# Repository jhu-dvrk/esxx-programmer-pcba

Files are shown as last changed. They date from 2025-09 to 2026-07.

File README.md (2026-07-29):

# ESXX Programmer PCB

This repository contains the KiCad design files for the ESXX Programmer board (previously called ESPM Programmer). This board was originally developed to reprogram the FPGA on the ESPM board inside the PSM and ECM in the dVRK-Si system.

It is now also used to reprogram the FPGA on the ESSJ board inside the PSM and ECM setup joints in a full dVRK-Si system.

This board is connected to the JTAG port on the ESPM or ESSJ via a custom cable. Instructions for making the cable are in `dvrk-s-programmer-cable.pptx`.

The current firmware for this board is in [this repository](https://github.com/jhu-dvrk/esxx-programmer-firmware).  Previous versions (for ESPM Programmer) have been archived [here](https://github.com/jhu-dvrk/espm-programmer-firmware).

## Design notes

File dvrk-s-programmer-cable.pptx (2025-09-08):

## Wire harness assy, ESPM programmer

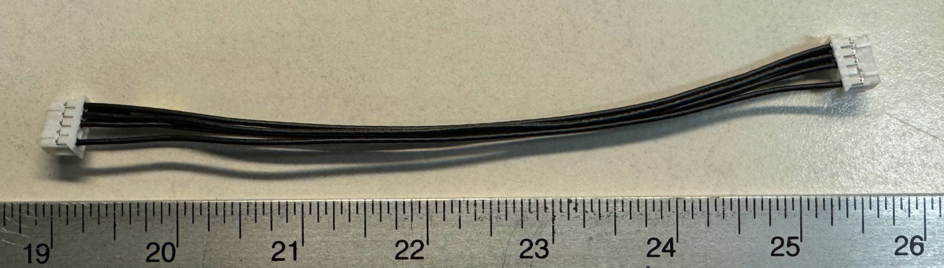
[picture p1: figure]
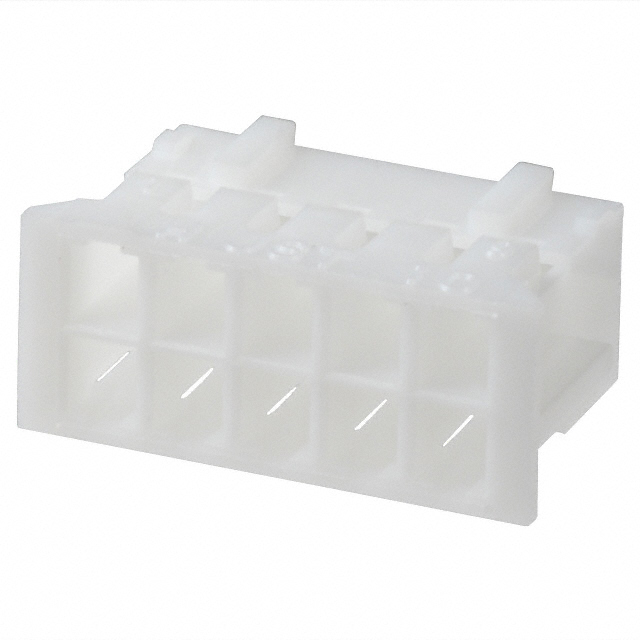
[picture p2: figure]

455-1158-ND
JST PHD 2x5
Qty 2

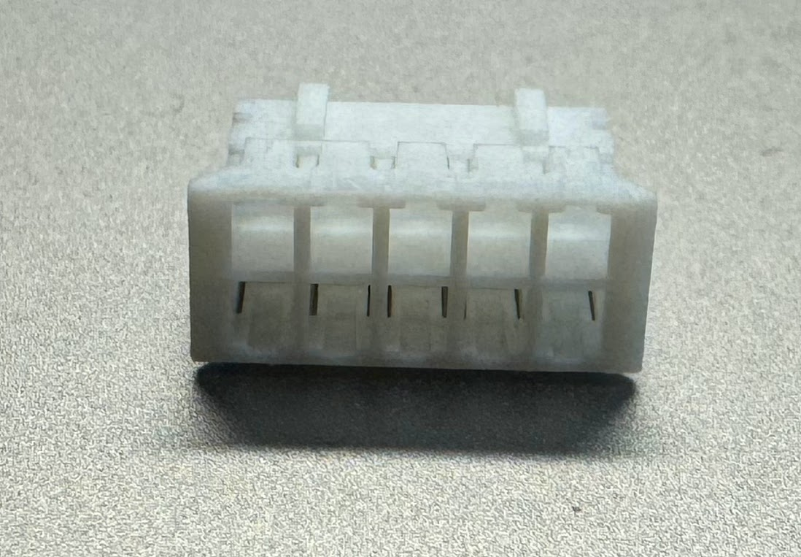
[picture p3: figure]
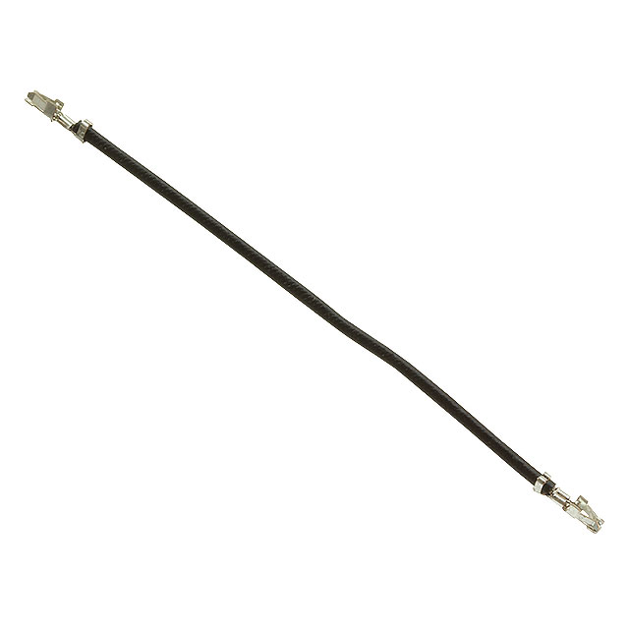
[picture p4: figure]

Precrimped
455-3085-ND
PHD 24 AWG
Qty 6

Apply a 10 mm section of yellow heat shrink tube on this end

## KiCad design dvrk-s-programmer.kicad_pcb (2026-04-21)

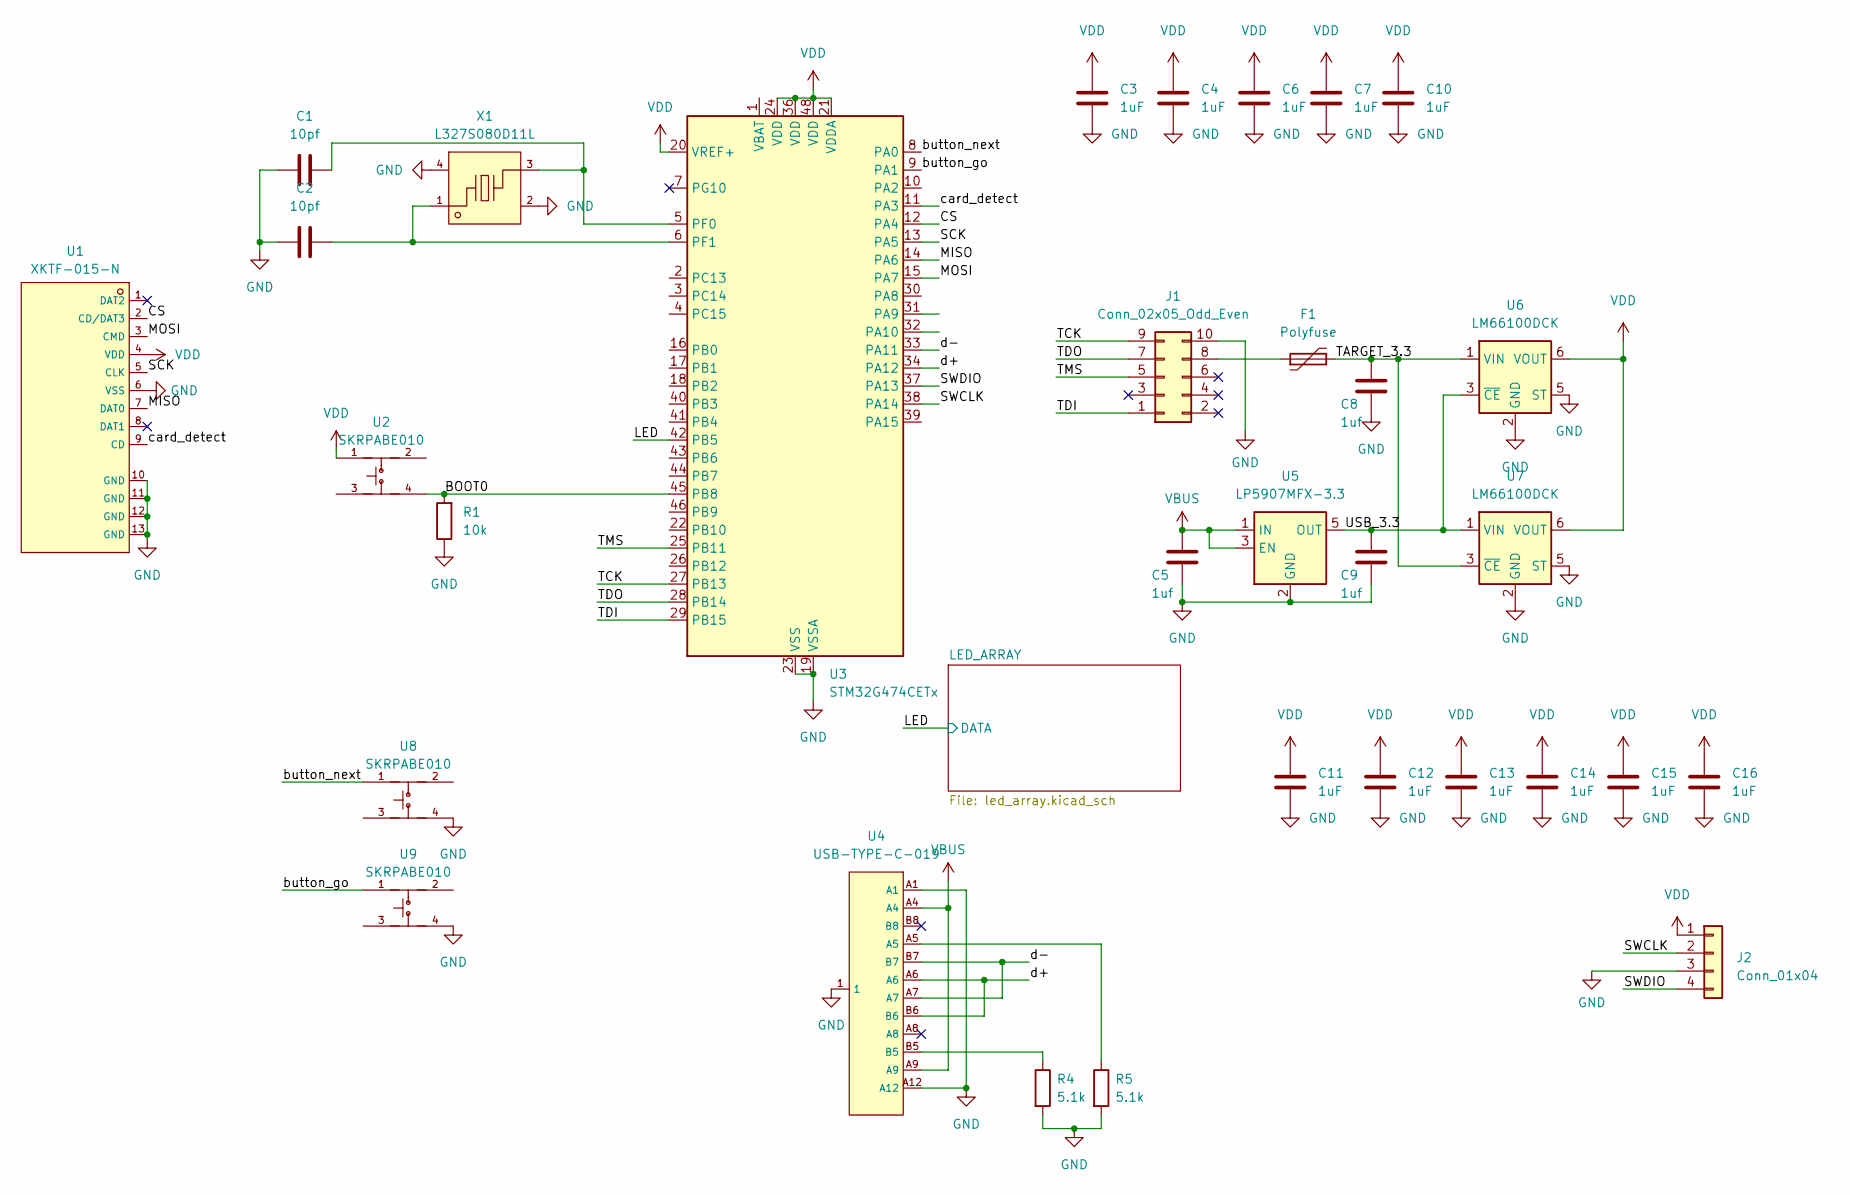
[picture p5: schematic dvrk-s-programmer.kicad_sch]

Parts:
C1, C2: 10pf; C_0402_1005Metric; LCSC C32949
C3, C4, C6, C7, C10, C11, C12, C13, C14, C15, C16: 1uF; C_0402_1005Metric
C5, C8, C9: 1uf; C_0402_1005Metric; LCSC C52923
F1: Polyfuse; Fuse_0805_2012Metric
J1: Conn_02x05_Odd_Even; JST_PHD_S10B-PHDSS_2x05_P2.00mm_Horizontal
J2: Conn_01x04; PinHeader_1x04_P2.54mm_Vertical
R1: 10k; R_0402_1005Metric; LCSC C25744
R4, R5: 5.1k; R_0402_1005Metric; LCSC C25905
U1: XKTF-015-N; TF-SMD_XKTF-015-N; LCSC C381082
U2, U8, U9: SKRPABE010; KEY-SMD_4P-L4.2-W3.2-P2.20-LS4.6; LCSC C115360
U3: STM32G474CETx; LQFP-48_7x7mm_P0.5mm; LCSC C730125
U4: USB-TYPE-C-019; TYPE-C-SMD_HX-TYPE-C-16PIN; LCSC C2927039
U5: LP5907MFX-3.3; SOT-23-5; LCSC C80670
U6, U7: LM66100DCK; SOT-363_SC-70-6
X1: L327S080D11L; CRYSTAL-SMD_4P-L3.2-W2.5-BL; LCSC C5261255

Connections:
/BOOT0: R1.2, U2.4, U3.45 (PB8)
/CS: U1.2 (CD/DAT3), U3.12 (PA4)
/LED: U3.42 (PB5); also elsewhere on the board
/MISO: U1.7 (DAT0), U3.14 (PA6)
/MOSI: U1.3 (CMD), U3.15 (PA7)
/SCK: U1.5 (CLK), U3.13 (PA5)
/SWCLK: J2.2, U3.38 (PA14)
/SWDIO: J2.4, U3.37 (PA13)
/TARGET_3.3: C8.2, F1.2, U6.1 (VIN), U7.3 (~CE)
/TCK: J1.9, U3.27 (PB13)
/TDI: J1.1, U3.29 (PB15)
/TDO: J1.7, U3.28 (PB14)
/TMS: J1.5, U3.25 (PB11)
/USB_3.3: C9.2, U5.5 (OUT), U6.3 (~CE), U7.1 (VIN)
/button_go: U3.9 (PA1), U9.1
/button_next: U3.8 (PA0), U8.1
/card_detect: U1.9 (CD), U3.11 (PA3)
/d+: U3.34 (PA12), U4.A6, U4.B6
/d-: U3.33 (PA11), U4.A7, U4.B7
GND: C1.1, C2.1, C3.2, C4.2, C5.1, C6.2, C7.2, C8.1, C9.1, C10.2, C11.2, C12.2, C13.2, C14.2, C15.2, C16.2, J1.10, J2.3, R1.1, R4.2, R5.2, U1.6 (VSS), U1.10 (GND), U1.11 (GND), U1.12 (GND), U1.13 (GND), U3.19 (VSSA), U3.23 (VSS), U3.35 (VSS), U3.47 (VSS), U4.1, U4.A1, U4.A12, U5.2 (GND), U6.2 (GND), U6.5 (ST), U7.2 (GND), U7.5 (ST), U8.4, U9.4, X1.2 (GND), X1.4 (GND); also elsewhere on the board
unnamed: F1.1, J1.8
unnamed: R4.1, U4.B5
unnamed: R5.1, U4.A5
unnamed: C1.2, U3.5 (PF0), X1.3
unnamed: C2.2, U3.6 (PF1), X1.1
VBUS: C5.2, U4.A4, U4.A9, U5.1 (IN), U5.3 (EN)
VDD: C3.1, C4.1, C6.1, C7.1, C10.1, C11.1, C12.1, C13.1, C14.1, C15.1, C16.1, J2.1, U1.4 (VDD), U2.1, U3.20 (VREF+), U3.21 (VDDA), U3.24 (VDD), U3.36 (VDD), U3.48 (VDD), U6.6 (VOUT), U7.6 (VOUT); also elsewhere on the board

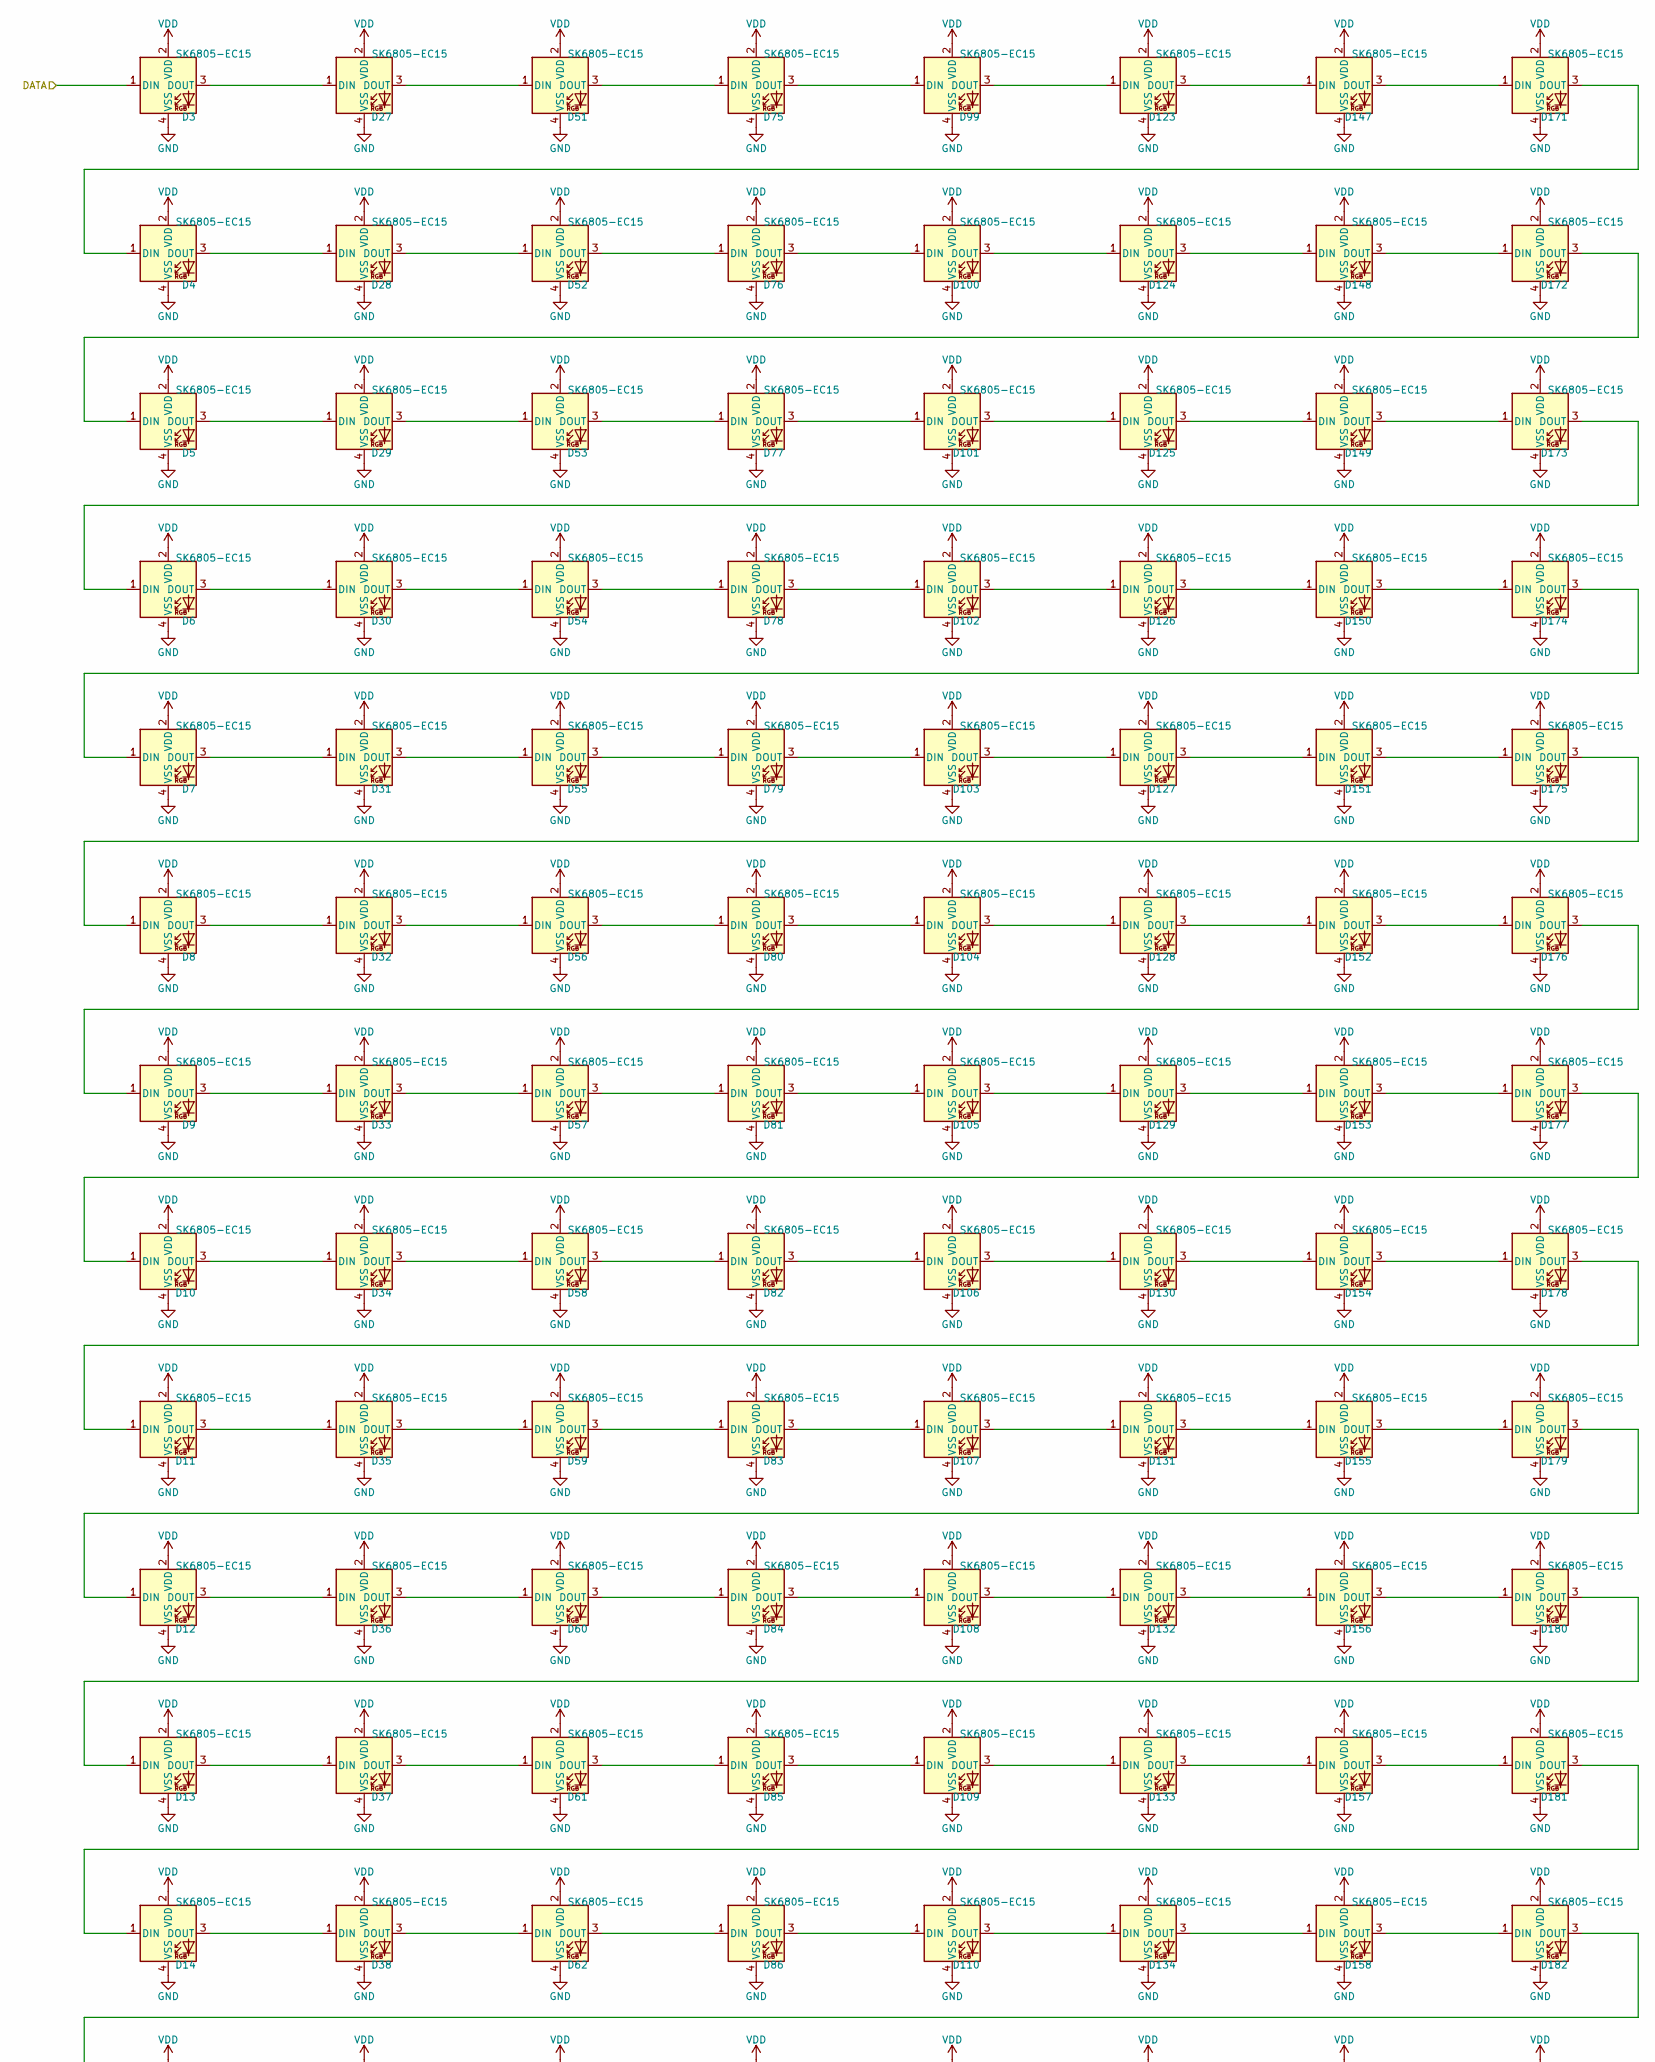
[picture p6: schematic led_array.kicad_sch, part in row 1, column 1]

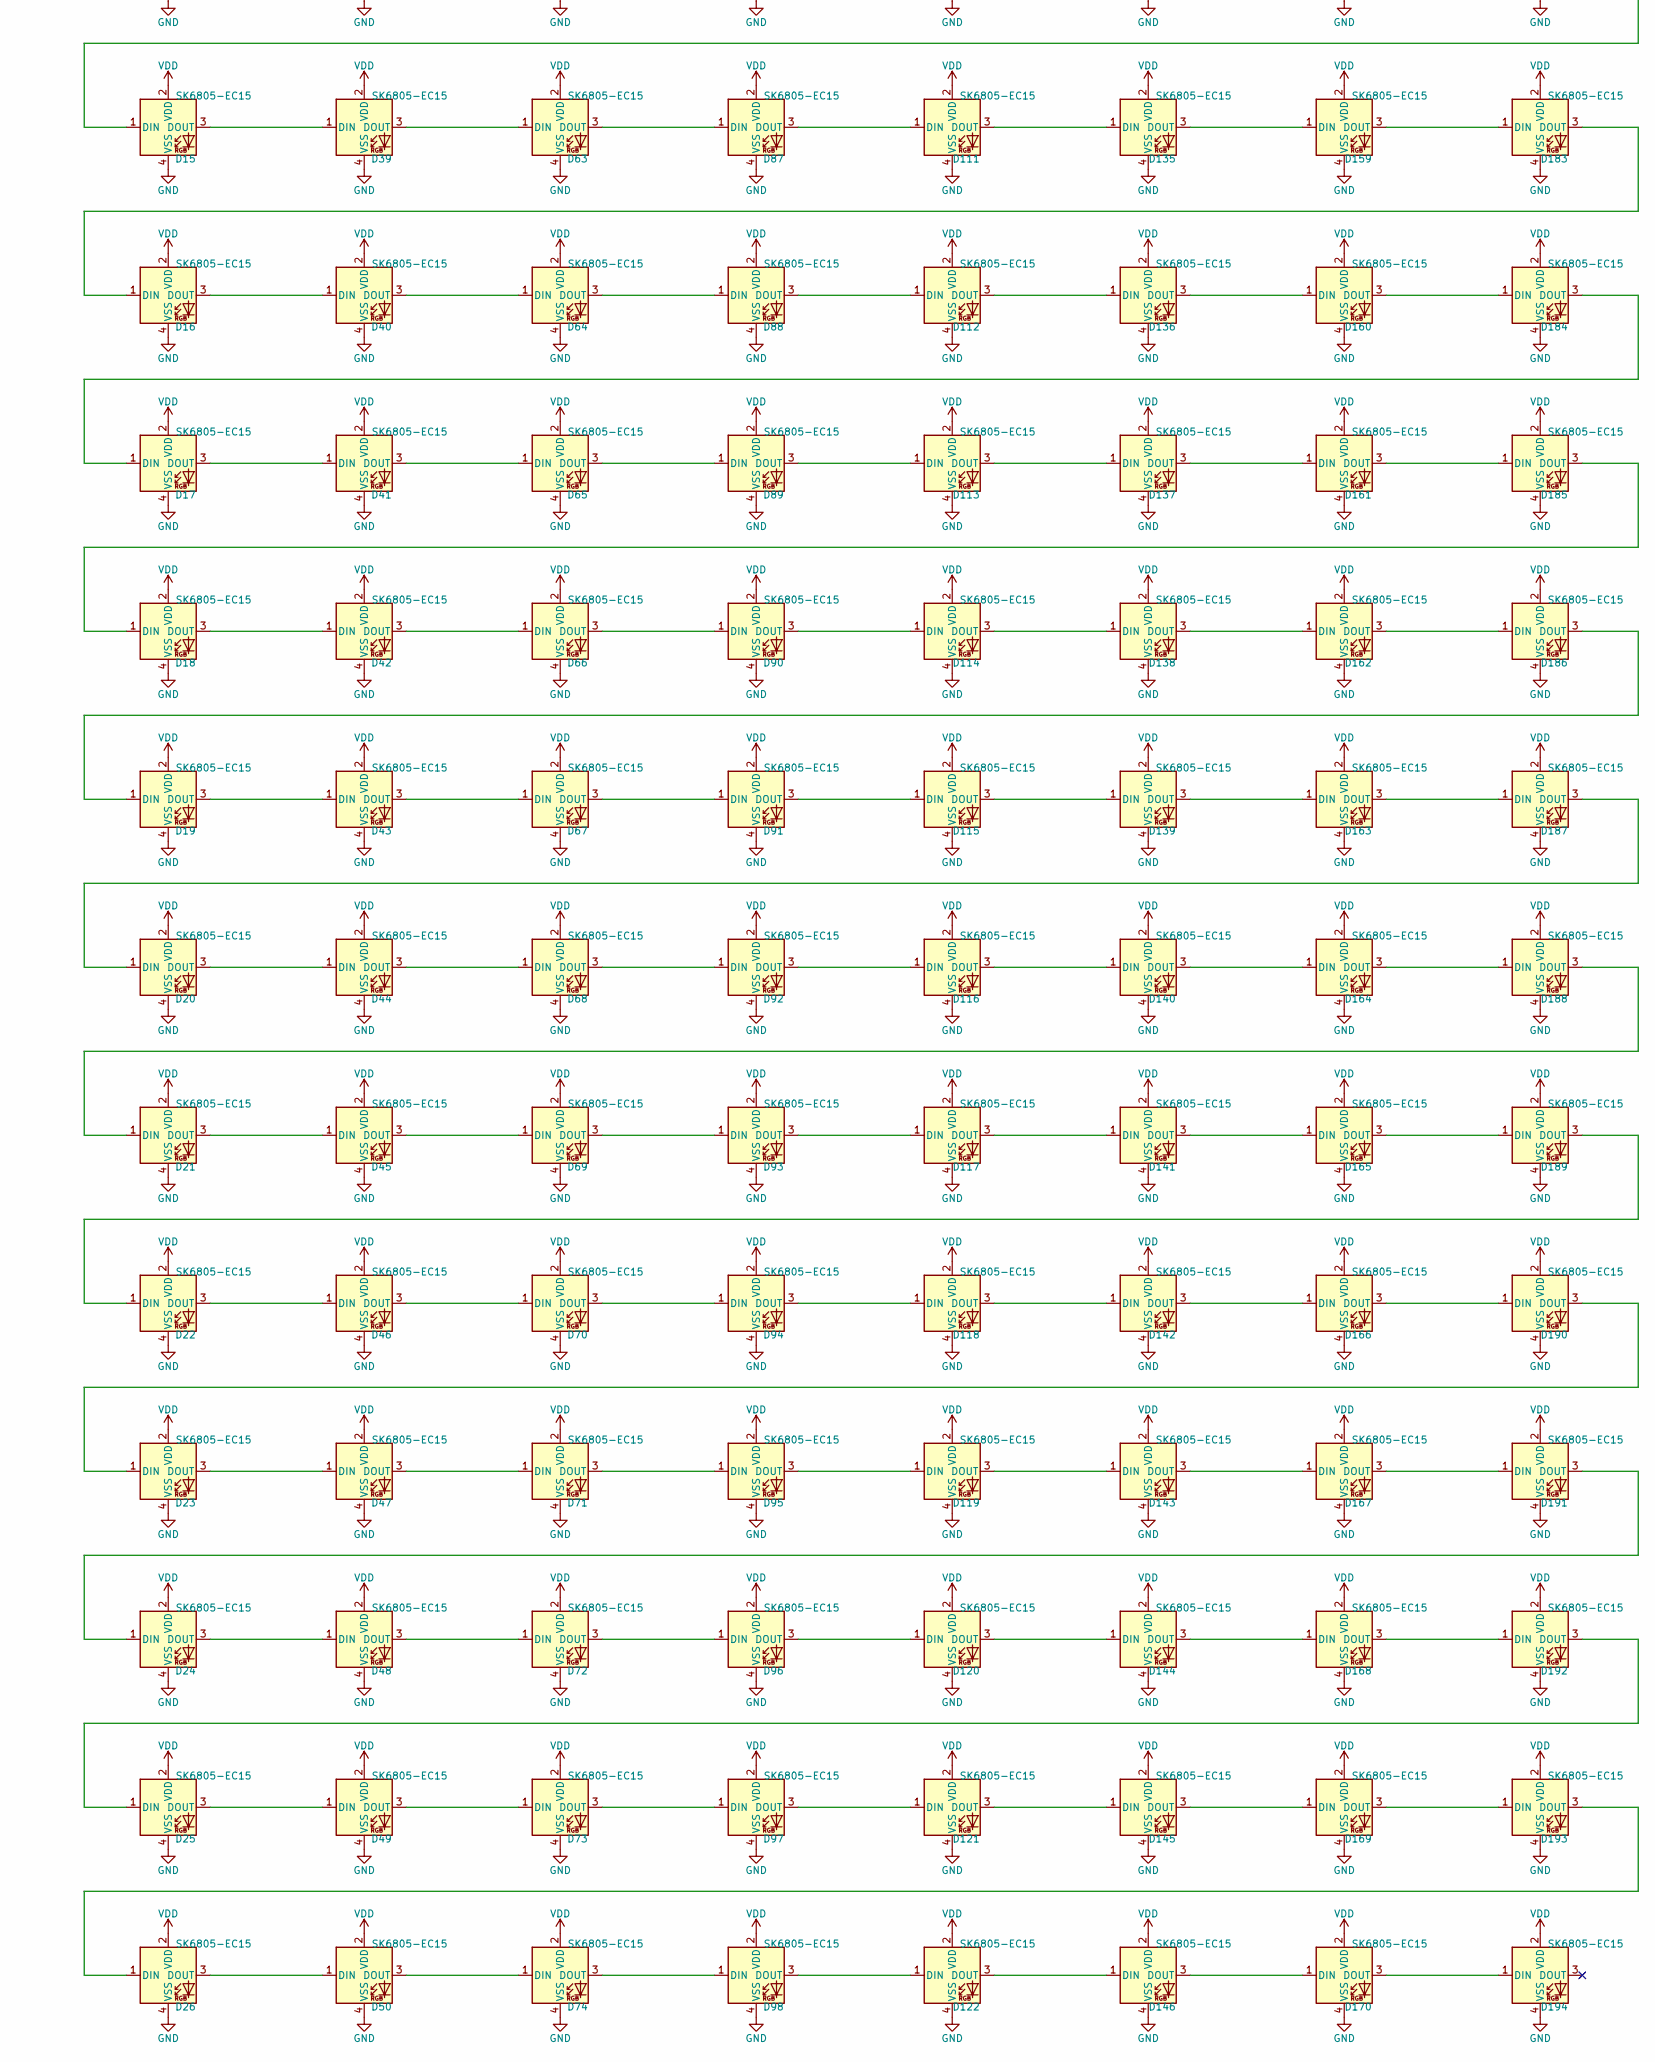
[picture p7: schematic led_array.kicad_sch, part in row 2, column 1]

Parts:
D3, D4, D5, D6, D7, D8, D9, D10, D11, D12, D13, D14, D15, D16, D17, D18, D19, D20, D21, D22, D23, D24, D25, D26, D27, D28, D29, D30, D31, D32, D33, D34, D35, D36, D37, D38, D39, D40, D41, D42, D43, D44, D45, D46, D47, D48, D49, D50, D51, D52, D53, D54, D55, D56, D57, D58, D59, D60, D61, D62, D63, D64, D65, D66, D67, D68, D69, D70, D71, D72, D73, D74, D75, D76, D77, D78, D79, D80, D81, D82, D83, D84, D85, D86, D87, D88, D89, D90, D91, D92, D93, D94, D95, D96, D97, D98, D99, D100, D101, D102, D103, D104, D105, D106, D107, D108, D109, D110, D111, D112, D113, D114, D115, D116, D117, D118, D119, D120, D121, D122, D123, D124, D125, D126, D127, D128, D129, D130, D131, D132, D133, D134, D135, D136, D137, D138, D139, D140, D141, D142, D143, D144, D145, D146, D147, D148, D149, D150, D151, D152, D153, D154, D155, D156, D157, D158, D159, D160, D161, D162, D163, D164, D165, D166, D167, D168, D169, D170, D171, D172, D173, D174, D175, D176, D177, D178, D179, D180, D181, D182, D183, D184, D185, D186, D187, D188, D189, D190, D191, D192, D193, D194: SK6805-EC15

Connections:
/LED: D3.1 (DIN); also elsewhere on the board
GND: D3.4 (VSS), D4.4 (VSS), D5.4 (VSS), D6.4 (VSS), D7.4 (VSS), D8.4 (VSS), D9.4 (VSS), D10.4 (VSS), D11.4 (VSS), D12.4 (VSS), D13.4 (VSS), D14.4 (VSS), D15.4 (VSS), D16.4 (VSS), D17.4 (VSS), D18.4 (VSS), D19.4 (VSS), D20.4 (VSS), D21.4 (VSS), D22.4 (VSS), D23.4 (VSS), D24.4 (VSS), D25.4 (VSS), D26.4 (VSS), D27.4 (VSS), D28.4 (VSS), D29.4 (VSS), D30.4 (VSS), D31.4 (VSS), D32.4 (VSS), D33.4 (VSS), D34.4 (VSS), D35.4 (VSS), D36.4 (VSS), D37.4 (VSS), D38.4 (VSS), D39.4 (VSS), D40.4 (VSS), D41.4 (VSS), D42.4 (VSS), D43.4 (VSS), D44.4 (VSS), D45.4 (VSS), D46.4 (VSS), D47.4 (VSS), D48.4 (VSS), D49.4 (VSS), D50.4 (VSS), D51.4 (VSS), D52.4 (VSS), D53.4 (VSS), D54.4 (VSS), D55.4 (VSS), D56.4 (VSS), D57.4 (VSS), D58.4 (VSS), D59.4 (VSS), D60.4 (VSS), D61.4 (VSS), D62.4 (VSS), D63.4 (VSS), D64.4 (VSS), D65.4 (VSS), D66.4 (VSS), D67.4 (VSS), D68.4 (VSS), D69.4 (VSS), D70.4 (VSS), D71.4 (VSS), D72.4 (VSS), D73.4 (VSS), D74.4 (VSS), D75.4 (VSS), D76.4 (VSS), D77.4 (VSS), D78.4 (VSS), D79.4 (VSS), D80.4 (VSS), D81.4 (VSS), D82.4 (VSS), D83.4 (VSS), D84.4 (VSS), D85.4 (VSS), D86.4 (VSS), D87.4 (VSS), D88.4 (VSS), D89.4 (VSS), D90.4 (VSS), D91.4 (VSS), D92.4 (VSS), D93.4 (VSS), D94.4 (VSS), D95.4 (VSS), D96.4 (VSS), D97.4 (VSS), D98.4 (VSS), D99.4 (VSS), D100.4 (VSS), D101.4 (VSS), D102.4 (VSS), D103.4 (VSS), D104.4 (VSS), D105.4 (VSS), D106.4 (VSS), D107.4 (VSS), D108.4 (VSS), D109.4 (VSS), D110.4 (VSS), D111.4 (VSS), D112.4 (VSS), D113.4 (VSS), D114.4 (VSS), D115.4 (VSS), D116.4 (VSS), D117.4 (VSS), D118.4 (VSS), D119.4 (VSS), D120.4 (VSS), D121.4 (VSS), D122.4 (VSS), D123.4 (VSS), D124.4 (VSS), D125.4 (VSS), D126.4 (VSS), D127.4 (VSS), D128.4 (VSS), D129.4 (VSS), D130.4 (VSS), D131.4 (VSS), D132.4 (VSS), D133.4 (VSS), D134.4 (VSS), D135.4 (VSS), D136.4 (VSS), D137.4 (VSS), D138.4 (VSS), D139.4 (VSS), D140.4 (VSS), D141.4 (VSS), D142.4 (VSS), D143.4 (VSS), D144.4 (VSS), D145.4 (VSS), D146.4 (VSS), D147.4 (VSS), D148.4 (VSS), D149.4 (VSS), D150.4 (VSS), D151.4 (VSS), D152.4 (VSS), D153.4 (VSS), D154.4 (VSS), D155.4 (VSS), D156.4 (VSS), D157.4 (VSS), D158.4 (VSS), D159.4 (VSS), D160.4 (VSS), D161.4 (VSS), D162.4 (VSS), D163.4 (VSS), D164.4 (VSS), D165.4 (VSS), D166.4 (VSS), D167.4 (VSS), D168.4 (VSS), D169.4 (VSS), D170.4 (VSS), D171.4 (VSS), D172.4 (VSS), D173.4 (VSS), D174.4 (VSS), D175.4 (VSS), D176.4 (VSS), D177.4 (VSS), D178.4 (VSS), D179.4 (VSS), D180.4 (VSS), D181.4 (VSS), D182.4 (VSS), D183.4 (VSS), D184.4 (VSS), D185.4 (VSS), D186.4 (VSS), D187.4 (VSS), D188.4 (VSS), D189.4 (VSS), D190.4 (VSS), D191.4 (VSS), D192.4 (VSS), D193.4 (VSS), D194.4 (VSS); also elsewhere on the board
unnamed: D10.1 (DIN), D177.3 (DOUT)
unnamed: D10.3 (DOUT), D34.1 (DIN)
unnamed: D11.1 (DIN), D178.3 (DOUT)
unnamed: D11.3 (DOUT), D35.1 (DIN)
unnamed: D12.1 (DIN), D179.3 (DOUT)
unnamed: D12.3 (DOUT), D36.1 (DIN)
unnamed: D13.1 (DIN), D180.3 (DOUT)
unnamed: D13.3 (DOUT), D37.1 (DIN)
unnamed: D14.1 (DIN), D181.3 (DOUT)
unnamed: D14.3 (DOUT), D38.1 (DIN)
unnamed: D15.1 (DIN), D182.3 (DOUT)
unnamed: D15.3 (DOUT), D39.1 (DIN)
unnamed: D16.1 (DIN), D183.3 (DOUT)
unnamed: D16.3 (DOUT), D40.1 (DIN)
unnamed: D17.1 (DIN), D184.3 (DOUT)
unnamed: D17.3 (DOUT), D41.1 (DIN)
unnamed: D18.1 (DIN), D185.3 (DOUT)
unnamed: D18.3 (DOUT), D42.1 (DIN)
unnamed: D19.3 (DOUT), D43.1 (DIN)
unnamed: D20.3 (DOUT), D44.1 (DIN)
unnamed: D21.3 (DOUT), D45.1 (DIN)
unnamed: D22.3 (DOUT), D46.1 (DIN)
unnamed: D23.3 (DOUT), D47.1 (DIN)
unnamed: D24.3 (DOUT), D48.1 (DIN)
unnamed: D25.3 (DOUT), D49.1 (DIN)
unnamed: D26.3 (DOUT), D50.1 (DIN)
unnamed: D3.3 (DOUT), D27.1 (DIN)
unnamed: D27.3 (DOUT), D51.1 (DIN)
unnamed: D4.3 (DOUT), D28.1 (DIN)
unnamed: D28.3 (DOUT), D52.1 (DIN)
unnamed: D5.3 (DOUT), D29.1 (DIN)
unnamed: D29.3 (DOUT), D53.1 (DIN)
unnamed: D6.3 (DOUT), D30.1 (DIN)
unnamed: D30.3 (DOUT), D54.1 (DIN)
unnamed: D7.3 (DOUT), D31.1 (DIN)
unnamed: D31.3 (DOUT), D55.1 (DIN)
unnamed: D8.3 (DOUT), D32.1 (DIN)
unnamed: D32.3 (DOUT), D56.1 (DIN)
unnamed: D9.3 (DOUT), D33.1 (DIN)
unnamed: D33.3 (DOUT), D57.1 (DIN)
unnamed: D34.3 (DOUT), D58.1 (DIN)
unnamed: D35.3 (DOUT), D59.1 (DIN)
unnamed: D36.3 (DOUT), D60.1 (DIN)
unnamed: D37.3 (DOUT), D61.1 (DIN)
unnamed: D38.3 (DOUT), D62.1 (DIN)
unnamed: D39.3 (DOUT), D63.1 (DIN)
unnamed: D40.3 (DOUT), D64.1 (DIN)
unnamed: D41.3 (DOUT), D65.1 (DIN)
unnamed: D42.3 (DOUT), D66.1 (DIN)
unnamed: D43.3 (DOUT), D67.1 (DIN)
unnamed: D44.3 (DOUT), D68.1 (DIN)
unnamed: D45.3 (DOUT), D69.1 (DIN)
unnamed: D46.3 (DOUT), D70.1 (DIN)
unnamed: D47.3 (DOUT), D71.1 (DIN)
unnamed: D48.3 (DOUT), D72.1 (DIN)
unnamed: D49.3 (DOUT), D73.1 (DIN)
unnamed: D50.3 (DOUT), D74.1 (DIN)
unnamed: D51.3 (DOUT), D75.1 (DIN)
unnamed: D52.3 (DOUT), D76.1 (DIN)
unnamed: D53.3 (DOUT), D77.1 (DIN)
unnamed: D54.3 (DOUT), D78.1 (DIN)
unnamed: D55.3 (DOUT), D79.1 (DIN)
unnamed: D56.3 (DOUT), D80.1 (DIN)
unnamed: D57.3 (DOUT), D81.1 (DIN)
unnamed: D58.3 (DOUT), D82.1 (DIN)
unnamed: D59.3 (DOUT), D83.1 (DIN)
unnamed: D60.3 (DOUT), D84.1 (DIN)
unnamed: D61.3 (DOUT), D85.1 (DIN)
unnamed: D62.3 (DOUT), D86.1 (DIN)
unnamed: D63.3 (DOUT), D87.1 (DIN)
unnamed: D64.3 (DOUT), D88.1 (DIN)
unnamed: D65.3 (DOUT), D89.1 (DIN)
unnamed: D66.3 (DOUT), D90.1 (DIN)
unnamed: D67.3 (DOUT), D91.1 (DIN)
unnamed: D68.3 (DOUT), D92.1 (DIN)
unnamed: D69.3 (DOUT), D93.1 (DIN)
unnamed: D70.3 (DOUT), D94.1 (DIN)
unnamed: D71.3 (DOUT), D95.1 (DIN)
unnamed: D72.3 (DOUT), D96.1 (DIN)
unnamed: D73.3 (DOUT), D97.1 (DIN)
unnamed: D74.3 (DOUT), D98.1 (DIN)
unnamed: D75.3 (DOUT), D99.1 (DIN)
unnamed: D76.3 (DOUT), D100.1 (DIN)
unnamed: D100.3 (DOUT), D124.1 (DIN)
unnamed: D77.3 (DOUT), D101.1 (DIN)
unnamed: D101.3 (DOUT), D125.1 (DIN)
unnamed: D78.3 (DOUT), D102.1 (DIN)
unnamed: D102.3 (DOUT), D126.1 (DIN)
unnamed: D79.3 (DOUT), D103.1 (DIN)
unnamed: D103.3 (DOUT), D127.1 (DIN)
unnamed: D80.3 (DOUT), D104.1 (DIN)
unnamed: D104.3 (DOUT), D128.1 (DIN)
unnamed: D81.3 (DOUT), D105.1 (DIN)
unnamed: D105.3 (DOUT), D129.1 (DIN)
unnamed: D82.3 (DOUT), D106.1 (DIN)
unnamed: D106.3 (DOUT), D130.1 (DIN)
unnamed: D83.3 (DOUT), D107.1 (DIN)
unnamed: D107.3 (DOUT), D131.1 (DIN)
unnamed: D84.3 (DOUT), D108.1 (DIN)
unnamed: D108.3 (DOUT), D132.1 (DIN)
unnamed: D85.3 (DOUT), D109.1 (DIN)
unnamed: D109.3 (DOUT), D133.1 (DIN)
unnamed: D86.3 (DOUT), D110.1 (DIN)
unnamed: D110.3 (DOUT), D134.1 (DIN)
unnamed: D87.3 (DOUT), D111.1 (DIN)
unnamed: D111.3 (DOUT), D135.1 (DIN)
unnamed: D88.3 (DOUT), D112.1 (DIN)
unnamed: D112.3 (DOUT), D136.1 (DIN)
unnamed: D89.3 (DOUT), D113.1 (DIN)
unnamed: D113.3 (DOUT), D137.1 (DIN)
unnamed: D90.3 (DOUT), D114.1 (DIN)
unnamed: D114.3 (DOUT), D138.1 (DIN)
unnamed: D91.3 (DOUT), D115.1 (DIN)
unnamed: D115.3 (DOUT), D139.1 (DIN)
unnamed: D92.3 (DOUT), D116.1 (DIN)
unnamed: D116.3 (DOUT), D140.1 (DIN)
unnamed: D93.3 (DOUT), D117.1 (DIN)
unnamed: D117.3 (DOUT), D141.1 (DIN)
unnamed: D94.3 (DOUT), D118.1 (DIN)
unnamed: D118.3 (DOUT), D142.1 (DIN)
unnamed: D95.3 (DOUT), D119.1 (DIN)
unnamed: D119.3 (DOUT), D143.1 (DIN)
unnamed: D96.3 (DOUT), D120.1 (DIN)
unnamed: D120.3 (DOUT), D144.1 (DIN)
unnamed: D97.3 (DOUT), D121.1 (DIN)
unnamed: D121.3 (DOUT), D145.1 (DIN)
unnamed: D98.3 (DOUT), D122.1 (DIN)
unnamed: D122.3 (DOUT), D146.1 (DIN)
unnamed: D99.3 (DOUT), D123.1 (DIN)
unnamed: D123.3 (DOUT), D147.1 (DIN)
unnamed: D124.3 (DOUT), D148.1 (DIN)
unnamed: D125.3 (DOUT), D149.1 (DIN)
unnamed: D126.3 (DOUT), D150.1 (DIN)
unnamed: D127.3 (DOUT), D151.1 (DIN)
unnamed: D128.3 (DOUT), D152.1 (DIN)
unnamed: D129.3 (DOUT), D153.1 (DIN)
unnamed: D130.3 (DOUT), D154.1 (DIN)
unnamed: D131.3 (DOUT), D155.1 (DIN)
unnamed: D132.3 (DOUT), D156.1 (DIN)
unnamed: D133.3 (DOUT), D157.1 (DIN)
unnamed: D134.3 (DOUT), D158.1 (DIN)
unnamed: D135.3 (DOUT), D159.1 (DIN)
unnamed: D136.3 (DOUT), D160.1 (DIN)
unnamed: D137.3 (DOUT), D161.1 (DIN)
unnamed: D138.3 (DOUT), D162.1 (DIN)
unnamed: D139.3 (DOUT), D163.1 (DIN)
unnamed: D140.3 (DOUT), D164.1 (DIN)
unnamed: D141.3 (DOUT), D165.1 (DIN)
unnamed: D142.3 (DOUT), D166.1 (DIN)
unnamed: D143.3 (DOUT), D167.1 (DIN)
unnamed: D144.3 (DOUT), D168.1 (DIN)
unnamed: D145.3 (DOUT), D169.1 (DIN)
unnamed: D146.3 (DOUT), D170.1 (DIN)
unnamed: D147.3 (DOUT), D171.1 (DIN)
unnamed: D148.3 (DOUT), D172.1 (DIN)
unnamed: D149.3 (DOUT), D173.1 (DIN)
unnamed: D150.3 (DOUT), D174.1 (DIN)
unnamed: D151.3 (DOUT), D175.1 (DIN)
unnamed: D152.3 (DOUT), D176.1 (DIN)
unnamed: D153.3 (DOUT), D177.1 (DIN)
unnamed: D154.3 (DOUT), D178.1 (DIN)
unnamed: D155.3 (DOUT), D179.1 (DIN)
unnamed: D156.3 (DOUT), D180.1 (DIN)
unnamed: D157.3 (DOUT), D181.1 (DIN)
unnamed: D158.3 (DOUT), D182.1 (DIN)
unnamed: D159.3 (DOUT), D183.1 (DIN)
unnamed: D160.3 (DOUT), D184.1 (DIN)
unnamed: D161.3 (DOUT), D185.1 (DIN)
unnamed: D162.3 (DOUT), D186.1 (DIN)
unnamed: D163.3 (DOUT), D187.1 (DIN)
unnamed: D164.3 (DOUT), D188.1 (DIN)
unnamed: D165.3 (DOUT), D189.1 (DIN)
unnamed: D166.3 (DOUT), D190.1 (DIN)
unnamed: D167.3 (DOUT), D191.1 (DIN)
unnamed: D168.3 (DOUT), D192.1 (DIN)
unnamed: D169.3 (DOUT), D193.1 (DIN)
unnamed: D170.3 (DOUT), D194.1 (DIN)
unnamed: D4.1 (DIN), D171.3 (DOUT)
unnamed: D5.1 (DIN), D172.3 (DOUT)
unnamed: D6.1 (DIN), D173.3 (DOUT)
unnamed: D7.1 (DIN), D174.3 (DOUT)
unnamed: D8.1 (DIN), D175.3 (DOUT)
unnamed: D9.1 (DIN), D176.3 (DOUT)
unnamed: D19.1 (DIN), D186.3 (DOUT)
unnamed: D20.1 (DIN), D187.3 (DOUT)
unnamed: D21.1 (DIN), D188.3 (DOUT)
unnamed: D22.1 (DIN), D189.3 (DOUT)
unnamed: D23.1 (DIN), D190.3 (DOUT)
unnamed: D24.1 (DIN), D191.3 (DOUT)
unnamed: D25.1 (DIN), D192.3 (DOUT)
unnamed: D26.1 (DIN), D193.3 (DOUT)
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

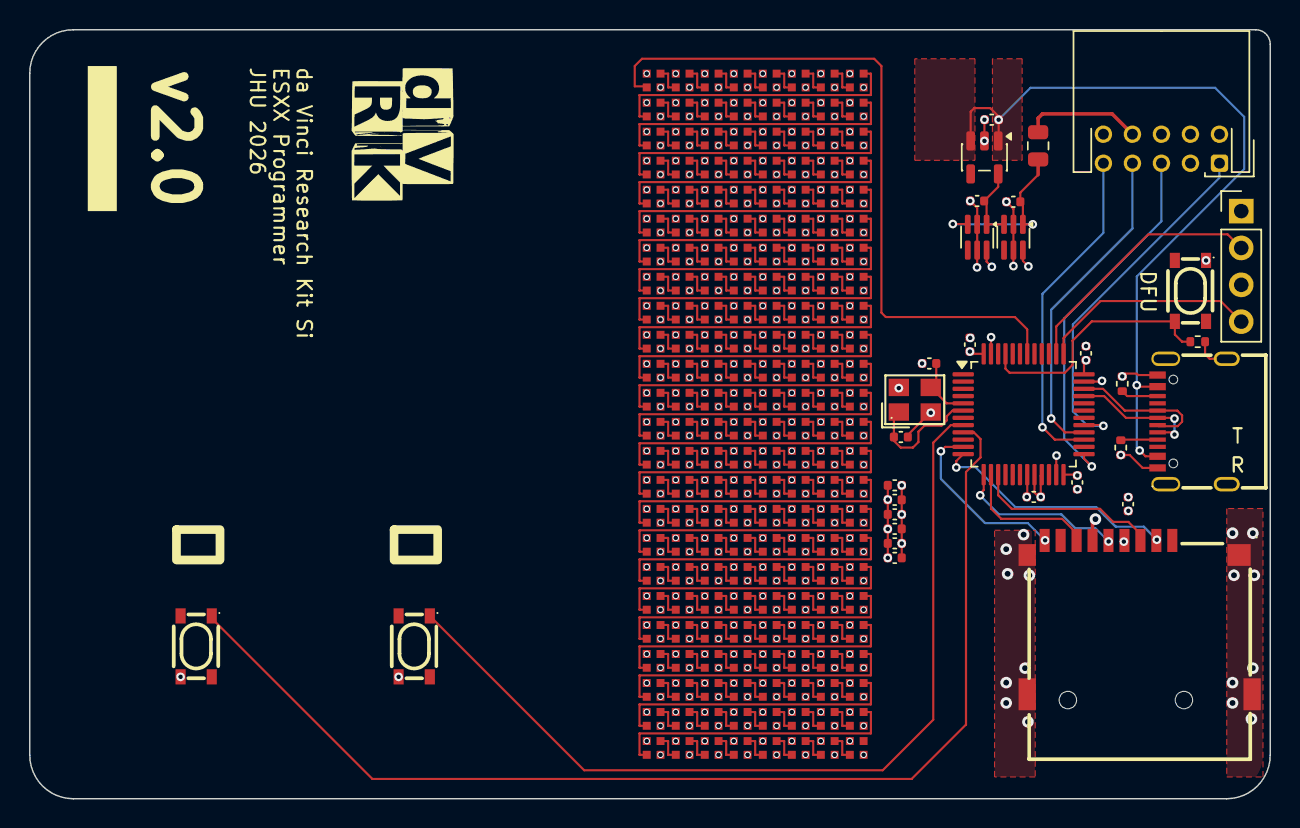
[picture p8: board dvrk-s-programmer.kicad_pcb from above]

Board: 4 copper layers, 85.5 x 53.0 mm, 224 parts (0 on the bottom side), 218 nets.

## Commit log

2025-09-08 Added README and programmer cable documentation
2026-03-17 changed mcu. added usb.
    [dvrk-s-programmer.kicad_sch]
2026-03-26 added led array. changed microcontroller.
    [dvrk-s-programmer.kicad_pcb, dvrk-s-programmer.kicad_sch, led_array.kicad_sch]
